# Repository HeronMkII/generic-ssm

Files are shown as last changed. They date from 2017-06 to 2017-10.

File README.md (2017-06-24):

# generic-ssm

KiCAD files to be used as a template when creating sub-system specific
PCBs.

## Instructions on using this repository as a template

First, clone this repository. Next, install [homebrew](https://brew.sh/) and run

```
$ brew install rename
```

In the root directory, run

```
$ ls . | rename -vs generic YOUR_SUBSYSTEM_NAME
```

For example, `rename -vs generic coms` creates files
`coms_ssm.kicad_pcb`, `coms_ssm.pro` and `coms_ssm.sch`.

Next, delete this git repository by running

```
$ rm -Rf .git/
```

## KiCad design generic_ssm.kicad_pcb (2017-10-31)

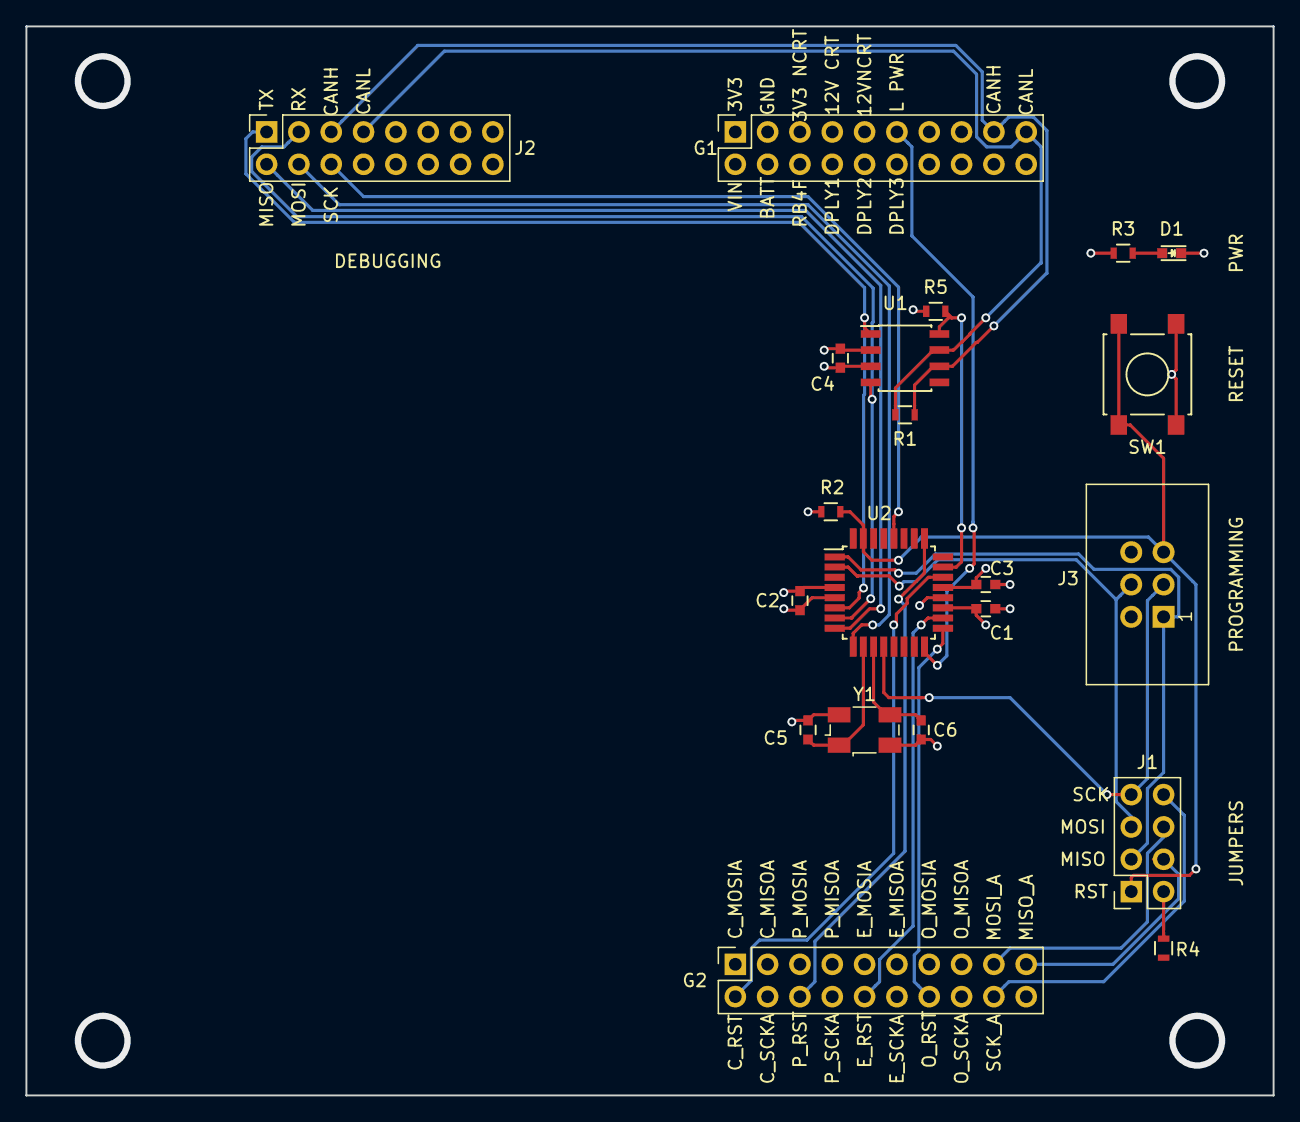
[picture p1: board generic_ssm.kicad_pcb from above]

Board: 4 copper layers, 98.0 x 84.0 mm, 21 parts (0 on the bottom side), 26 nets.

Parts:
C1, C2, C3: 0.1 uF; C_0603
C4: 0.1uF; C_0603
C5, C6: 22pF; C_0603
D1: PWR_LED; LED_0603
G1: GENERAL CONN 1; Socket_Strip_Straight_2x10_Pitch2.54mm
G2: GENERAL CONN 2; Socket_Strip_Straight_2x10_Pitch2.54mm
J1: RST_JMP; Socket_Strip_Straight_2x04_Pitch2.54mm
J2: DEBUG CONN; Socket_Strip_Straight_2x08_Pitch2.54mm
J3: PROGRAMMING PORT; IDC_Header_Straight_6pins
R1, R3, R4: 120R; R_0603
R2: 10K; R_0603
R5: 1K; R_0603
SW1: SW_RST; SW_SPST_B3S-1000
U1: SN65HVD230; SOIC-8_3.9x4.9mm_Pitch1.27mm
U2: ATMEGA32M1-MU; TQFP-32_7x7mm_Pitch0.8mm
Y1: 8MHz; Crystal_SMD_Abracon_ABM3B-4pin_5.0x3.2mm

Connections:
+3V3: C1.2, C2.2, C3.2, C4.1, G1.1, J3.2, R2.1, R3.1, U1.3, U2.4, U2.19, U2.21
/CANH: G1.17, J2.5, R1.1, U1.7
/CANL: G1.19, J2.7, R1.2, U1.6
/CAN_LPWR: R5.2, U1.8, U2.23
/COM_RST: G2.2, U2.22
/EPS_RST: G2.10, U2.18
/LOPWR: G1.11, U2.16
/MISO: J2.2, U2.8
/MISO_A: J1.3, J3.1, U2.1
/MISO_A_COMMON: G2.19, J1.4
/MOSI: J2.4, U2.9
/MOSI_A: J1.5, J3.4, U2.2
/MOSI_A_COMMON: G2.17, J1.6
/OBC_RST: G2.14, U2.17
/PAY_RST: G2.6, U2.25
/RST: J1.1, J3.5, R2.2, SW1.1, U2.31
/RX_CAN: J2.3, U1.4, U2.7
/SCK: J2.6, U2.28
/SCK_A: J1.7, J3.3, U2.12
/SCK_A_COMMON: G2.18, J1.8
/TX_CAN: J2.1, U1.1, U2.6
GND: C1.1, C2.1, C3.1, C4.2, C5.1, C6.1, D1.1, G1.3, J3.6, R5.1, SW1.2, U1.2, U2.5, U2.20, Y1.2, Y1.4
unnamed: C5.2, U2.10, Y1.1
unnamed: C6.2, U2.11, Y1.3
unnamed: D1.2, R3.2
unnamed: J1.2, R4.2

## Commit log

2017-06-24 Rename files for consistency
    [generic_ssm.kicad_pcb, generic_ssm.sch]
2017-08-13 Fixed for Flatsat 1
    Generic board. Read instructions on schematic to start building your
    own.
    Added G1, G2 common headers to stack boards on top of each other. Added
    standard debug header. Added power LED, reset pushbutton. Added
    decoupling caps on the power rails. Added jumper to enable/disable
    in-circuit reprogramming. Will think more about the reprogramming and
    reset lines to see how it can be done better - worst case they can all
    be disconnected. Changed to 4-pin crystal. Changed CAN transceiver
    footprint because old one was ugly. Please triple-check all schematics
    with your first iteration ones to see if I got everything right.
    [generic_ssm.sch]
2017-08-16 Created the PCB schematic
    [generic_ssm.sch]
2017-08-16 Ease-of-use changes to PCB routing.
    [generic_ssm.kicad_pcb]
2017-08-18 Minor Changes
    Fixed via sizes, fixed resistors on schematic
    [_saved_generic_ssm.sch, generic_ssm.kicad_pcb]
2017-08-18 Didn't save schematic properly last time
    [_saved_generic_ssm.sch, generic_ssm.sch]
2017-08-18 Lo Power
    Added lo power input to 32m1 gpio pin, added can low power mode
    functionality for new can transceiver (hvd230)
    [generic_ssm.sch]
2017-08-18 Minor fix
    deleted a no-connect
    [generic_ssm.sch]
2017-08-18 Remade PCB layout for different header positions.
    [generic_ssm.kicad_pcb, generic_ssm.sch]
2017-08-18 Touched up the silkscreen.
    [generic_ssm.kicad_pcb]
2017-08-20 Bugfixes to the PCB layout.
    [generic_ssm.kicad_pcb, generic_ssm.sch]
2017-10-31 Fixed the layout of the CAN transciever.
    [generic_ssm.sch]
2017-10-31 Updated PCB schematic with CAN fixes.
    [generic_ssm.kicad_pcb]
